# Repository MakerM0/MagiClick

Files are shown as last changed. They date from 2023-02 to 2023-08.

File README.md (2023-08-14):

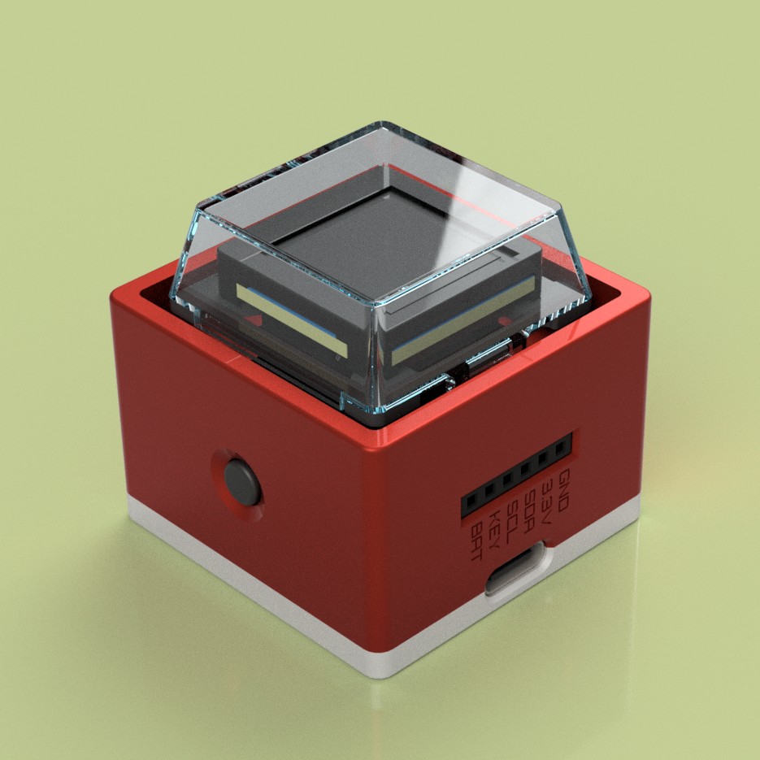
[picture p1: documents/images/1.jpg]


<p align="center">
    <br>
    
    <br>
</p>
<p align="center">   
    
      
</p>

# [MagiClick](https://hackaday.io/project/188183-magiclick-a-mechanical-button-with-screen)

[GitHub - MakerM0/MagiClick: A button](https://github.com/MakerM0/MagiClick)

The project uses [WCH&#39;s CH582F](https://www.wch.cn/products/CH583.html), a RISC-V chip, which supports BLE. The SDK comes with a multitasking system TMOS, which is very convenient for writing code.

The button can implement a variety of functions.
For example:

- Shutter via BLE
- Stopwatch
- Clock
- Pomodoro
- Music playback controller via BLE
- counter
- Random numbers
- 

It includes an expansion interface to support communication with I2C devices, such as temperature and humidity monitoring, light monitoring, etc.
You can achieve more depending on your needs.

## Guide

Power on: Press and hold the left button

Power off: In the function menu interface, hit the keys three times in a row

Switch function: On the function menu interface, press the side button to switch left and right

Return to the function options page: In general, press and hold the left or right button

Enter the function: The general situation is to press and hold the middle button

Use the apk under the software folder to synchronize time

## Firmware

IDE: [MounRiver Stuido](http://www.mounriver.com/download)

### How to download the firmware

TOOL: WCHISPStudio

While holding down the right button, press the left button to turn on the power, and you can enter the download mode

## Note

The current low-power strategy is to shut down the power directly. The time is not saved after the shutdown action. Please note.

In the future, standby mode will be adopted to maintain low power consumption and time functions.

## Mechanical

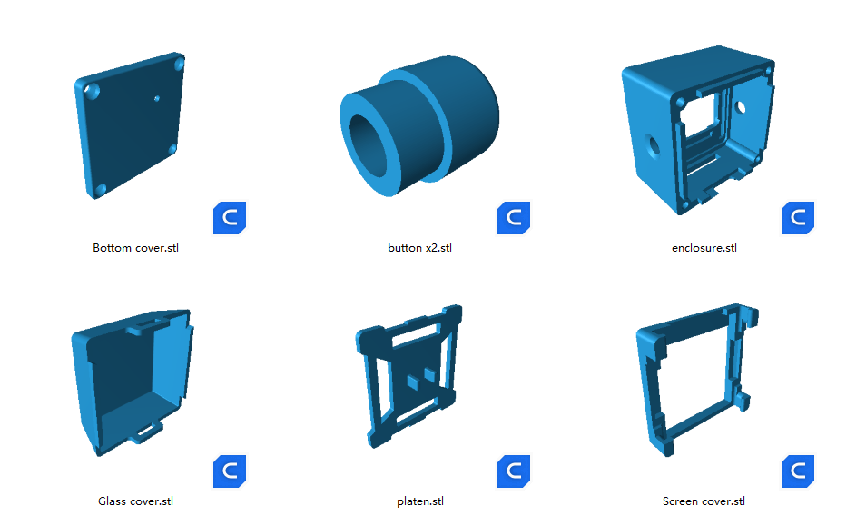
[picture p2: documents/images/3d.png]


The above file can be printed using a 3D printer.

The Glass cover must be transparent.

For Screen cover, black printing is recommended.

The screw hole is not used yet, please use glue to fix it.

I'll update the file that uses the screw holes when I'm free, hopefully not for too long.

## Images

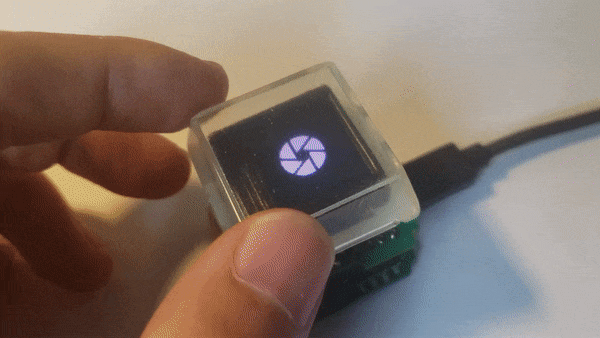
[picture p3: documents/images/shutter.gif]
shutter


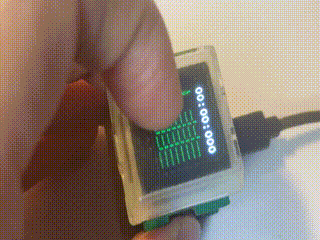
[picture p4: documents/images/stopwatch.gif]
stopwatch


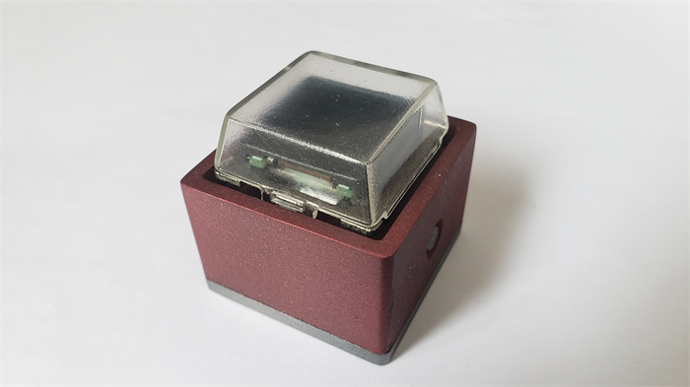
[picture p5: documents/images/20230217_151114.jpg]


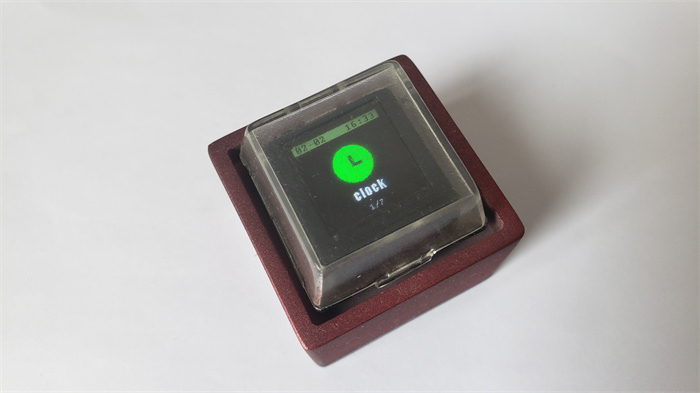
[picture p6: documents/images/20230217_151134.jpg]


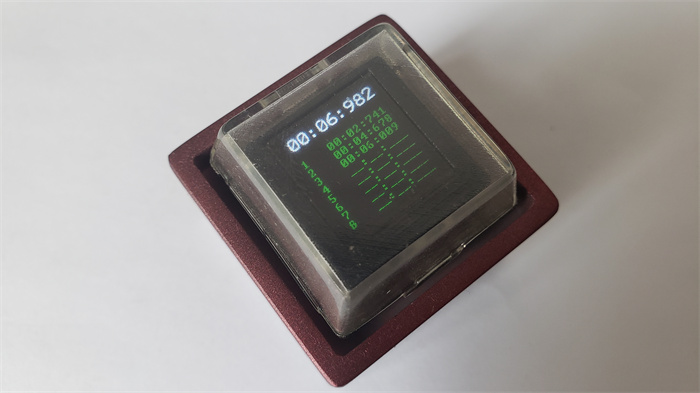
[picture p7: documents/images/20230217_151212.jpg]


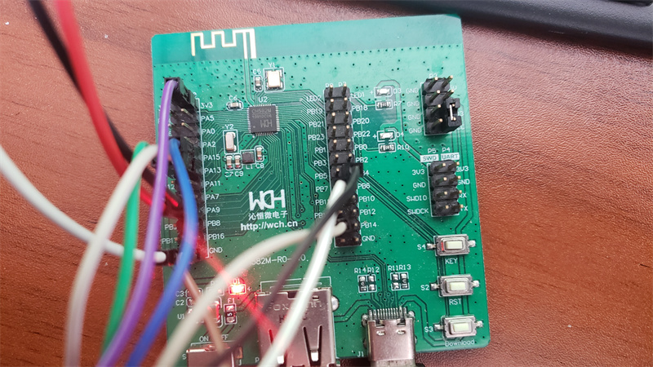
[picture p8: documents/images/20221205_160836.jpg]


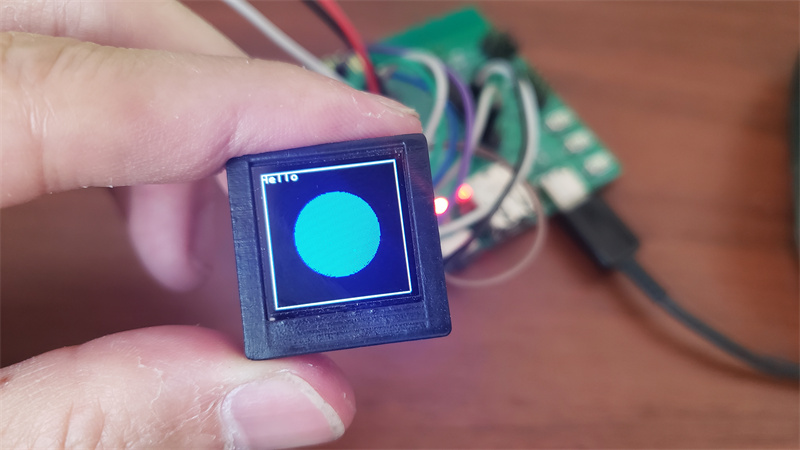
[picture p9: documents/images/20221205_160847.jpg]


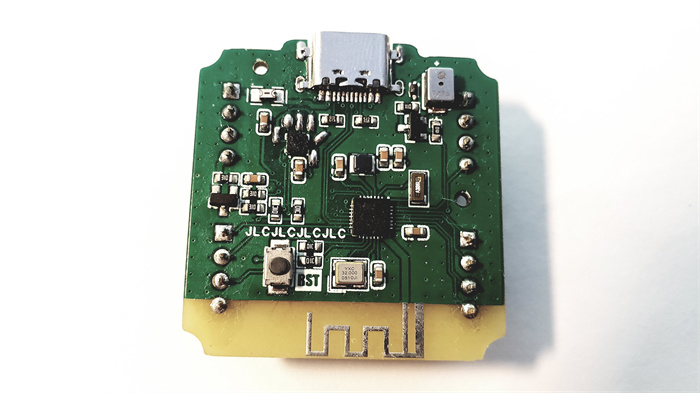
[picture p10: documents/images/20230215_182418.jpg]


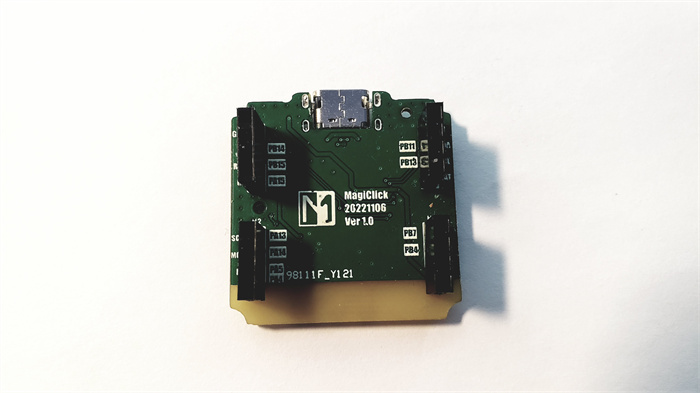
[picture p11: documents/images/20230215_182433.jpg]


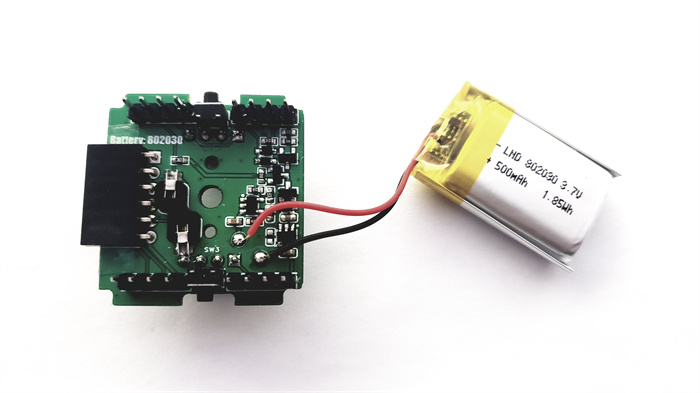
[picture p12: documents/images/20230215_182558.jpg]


## License

(hardware/mechanical)https://creativecommons.org/licenses/by-nc-nd/4.0

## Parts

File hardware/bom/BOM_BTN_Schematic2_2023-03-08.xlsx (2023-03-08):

No. | Quantity | Comment | Designator | Footprint | Value | Manufacturer Part | Manufacturer
1 | 2 | 10uF | C10,C11 | C0603 | 10uF | CL10A106KP8NNNC | SAMSUNG(三星)
2 | 2 | 1uF | C12,C13 | C0603 | 1uF | CL10A105KB8NNNC | SAMSUNG(三星)
3 | 3 | 1N5819WS | D1,D2,D3 | SOD-323_L1.8-W1.3-LS2.5-RD |  | 1N5819WS | Hottech(合科泰)
4 | 2 | 2.54-1*4P母 | H1,H2 | HDR-TH_4P-P2.54-V-F |  | 2.54-1*4P母 | BOOMELE(博穆精密)
5 | 4 | KH-2.54PH180-1X4P-L11.5 | H3,H4,H7,H8 | HDR-TH_4P-P2.54-V-M |  | KH-2.54PH180-1X4P-L11.5 | kinghelm(金航标)
6 | 1 | A2541HWR-6P | H5 | HDR-TH_6P-P2.54-H-W8.6_A2541HWR-6P |  | A2541HWR-6P | CJT(长江连接器)
7 | 1 | 19-217/R6C-AL1M2VY/3T | LED1 | LED0603-R-RD |  | 19-217/R6C-AL1M2VY/3T | EVERLIGHT(台湾亿光)
8 | 2 | AO3401A | Q1,Q2 | SOT-23_L2.9-W1.3-P1.90-LS2.4-BR |  | AO3401A | AOS
9 | 1 | AO3400A | Q3 | SOT-23-3_L2.9-W1.6-P1.90-LS2.8-BR |  | AO3400A | AOS
10 | 3 | 10kΩ | R1,R5,R6 | R0603 | 10kΩ | 0603WAF1002T5E | UNI-ROYAL(厚声)
11 | 3 | 100kΩ | R2,R3,R4 | R0603 | 100kΩ | 0603WAF1003T5E | UNI-ROYAL(厚声)
12 | 1 | 1kΩ | R16 | R0603 | 1kΩ | 0603WAF1001T5E | UNI-ROYAL(厚声)
13 | 1 | 0603WAF1601T5E | R17 | R0603 |  | 0603WAF1601T5E | UNI-ROYAL(厚声)
14 | 2 | ST-1109-3-5 | SW2,SW3 | SW-TH_ST-1109-3-5 |  | ST-1109-3-5 | RISHENG(日昇)
15 | 1 | CPG135001D03 | SW4 | 凯华矮轴 复合 热插拔 |  | CPG135001D03 | Kailh(凯华)
16 | 1 | TP4054-42-SOT25R | U1 | SOT-23-5_L3.0-W1.7-P0.95-LS2.8-BR |  | TP4054-42-SOT25R | TOPPOWER(南京拓微)
17 | 1 | ME6214C33M5G | U2 | SOT-23-5_L3.0-W1.7-P0.95-LS2.8-BR |  | ME6214C33M5G | MICRONE(南京微盟)

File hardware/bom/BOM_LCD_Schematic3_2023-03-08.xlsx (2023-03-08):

No. | Quantity | Comment | Designator | Footprint | Value | Manufacturer Part | Manufacturer
1 | 1 | 100nF | C1 | C0603 | 100nF | CL10B104KB8NNNC | SAMSUNG(三星)
2 | 1 | 1uF | C2 | c0603 | 1uF | CC0603KRX5R8BB105 | YAGEO(国巨)
3 | 2 | KH-2.54PH180-1X4P-L11.5 | H1,H2 | HDR-TH_4P-P2.54-V-M |  | KH-2.54PH180-1X4P-L11.5 | kinghelm(金航标)
4 | 1 | SS8050 | Q1 | SOT-23-3_L2.9-W1.3-P1.90-LS2.4-BR |  | SS8050 | CJ（江苏长电/长晶）
5 | 1 | 10Ω | R2 | R0603 | 10Ω | 0603WAF100JT5E | UNI-ROYAL(厚声)
6 | 1 | 10kΩ | R4 | R0603 | 10kΩ | 0603WAF1002T5E | UNI-ROYAL(厚声)
7 | 1 | 1kΩ | R5 | R0603 | 1kΩ | 0603WAF1001T5E | UNI-ROYAL(厚声)
8 | 1 |  | U1 | TFT_0.85inch_128*128

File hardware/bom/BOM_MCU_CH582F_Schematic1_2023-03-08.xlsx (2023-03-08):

No. | Quantity | Comment | Designator | Footprint | Value | Manufacturer Part | Manufacturer
1 | 1 | DET402-G-1 | BUZZER2 | BUZ-SMD_L4.0-W3.0-LS4.5-FD |  | DET402-G-1
2 | 4 | 2.2uF | C1,C2,C7,C8 | C0603 | 2.2uF | CL10A225KO8NNNC | SAMSUNG(三星)
3 | 4 | 100nF | C3,C4,C5,C6 | C0603 | 100nF | CL10B104KB8NNNC | SAMSUNG(三星)
4 | 1 | 1N4148WT | D3 | SOD-523_L1.2-W0.8-LS1.6-RD |  | 1N4148WT | onsemi(安森美)
5 | 1 | JK-SMD0805-050/6V | F1 | F0805 |  | JK-SMD0805-050/6V | JK(金科)
6 | 4 | 2.54-1*4P母 | H1,H2,H3,H4 | HDR-TH_4P-P2.54-V-F |  | 2.54-1*4P母 | BOOMELE(博穆精密)
7 | 6 | 2短路点 | J1,J2,J3,J4,J5,J6 | 短路接口
8 | 1 | 22uH | L1 | IND-SMD_L2.5-W2.0_FNR252012S | 22uH | FNR252012S220MT | cjiang(长江微电)
9 | 1 | AO3400A | Q1 | SOT-23_L2.9-W1.3-P1.90-LS2.4-BR |  | AO3400A | BORN伯恩半导体
10 | 1 | AO3401A | Q2 | SOT-23_L2.9-W1.3-P1.90-LS2.4-BR |  | AO3401A | AOS
11 | 2 | 5.1kΩ | R1,R2 | R0603 | 5.1kΩ | 0603WAF5101T5E | UNI-ROYAL(厚声)
12 | 4 | 10kΩ | R3,R4,R9,R10 | R0603 | 10kΩ | 0603WAF1002T5E | UNI-ROYAL(厚声)
13 | 3 | 1MΩ | R5,R6,R29 | R0603 | 1MΩ | 0603WAF1004T5E | UNI-ROYAL(厚声)
14 | 1 | 100kΩ | R7 | R0603 | 100kΩ | 0603WAF1003T5E | UNI-ROYAL(厚声)
15 | 1 | 10Ω | R8 | R0603 | 10Ω | 0603WAF100JT5E | UNI-ROYAL(厚声)
16 | 1 | TSA010A2026B | SW2 | SW-SMD_L4.0-W3.0-LS5.0 |  | TSA010A2026B | BZCN(博众电气)
17 | 1 | CH582F | U2 | QFN-28_L4.0-W4.0-P0.40-BL-EP2.8 |  | CH582F | WCH(南京沁恒)
18 | 1 | KXTJ3-1057 | U3 | LGA-12_L2.0-W2.0-P0.50-BL |  | KXTJ3-1057 | ROHM(罗姆)
19 | 1 | TYPE-C 16P CB1.6 073 | USB4 | USB-C-SMD_SHOU_TYPE-C-16P-CB1.6 |  | TYPE-C 16P CB1.6 073 | SHOU HAN(首韩)
20 | 1 | - | X1 | CRYSTAL-SMD_4P-L3.2-W2.5-BL | - | TZ0375A | TST(嘉硕)
21 | 1 | - | X2 | OSC-SMD_L3.2-W1.5 | - | DST310S 32.768KHz | KDS大真空

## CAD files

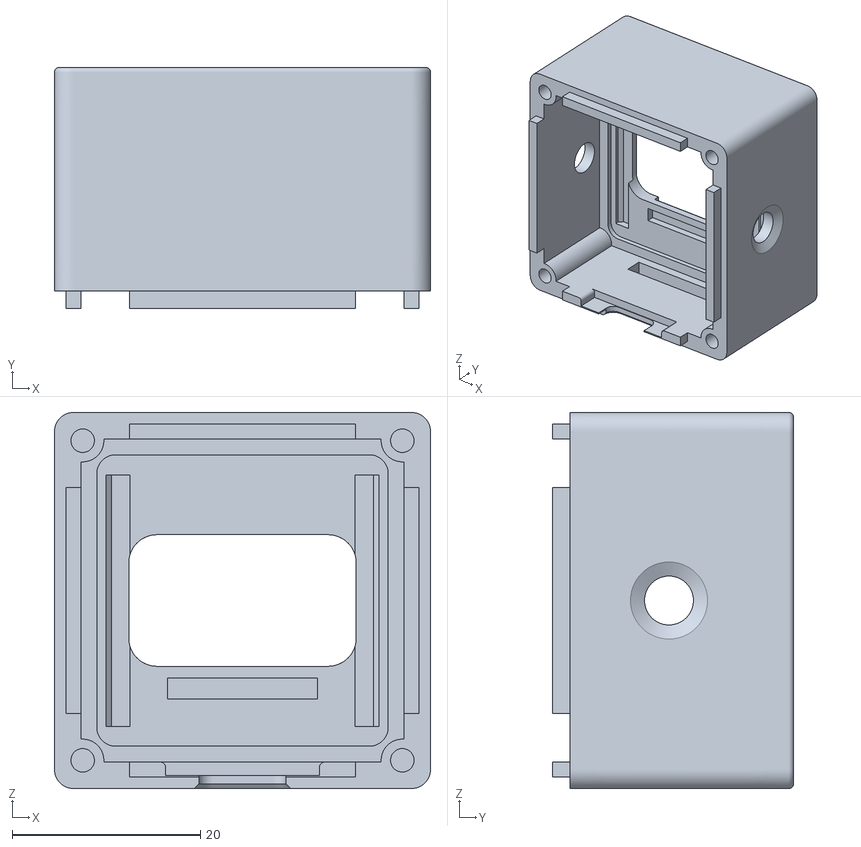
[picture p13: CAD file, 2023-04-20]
mechanical/v1.0/enclosure.stl
40.0 x 25.6 x 40.0

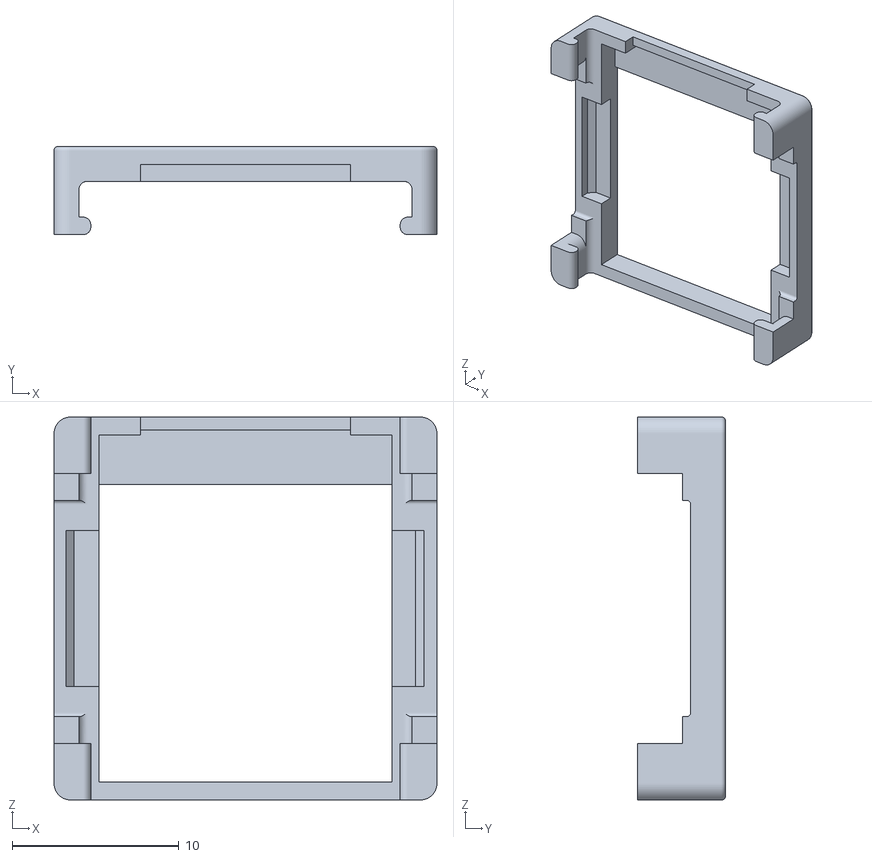
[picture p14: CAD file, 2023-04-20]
mechanical/v1.0/Screen cover.stl
23.0 x 5.30 x 23.0

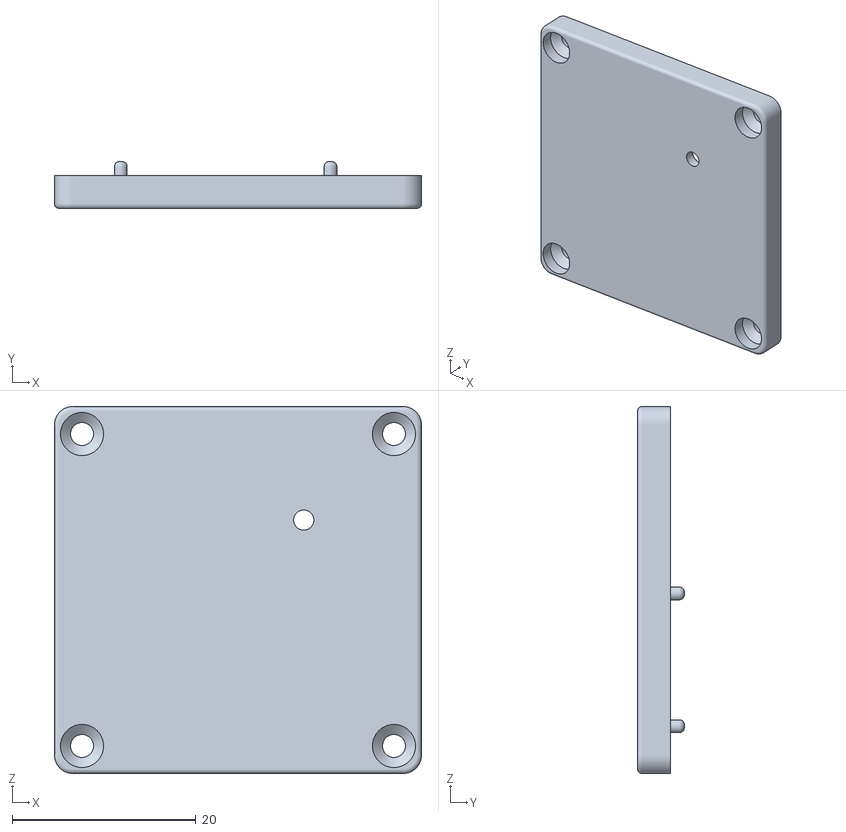
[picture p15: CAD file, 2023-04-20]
mechanical/v1.0/Bottom cover.stl
40.0 x 5.10 x 40.0

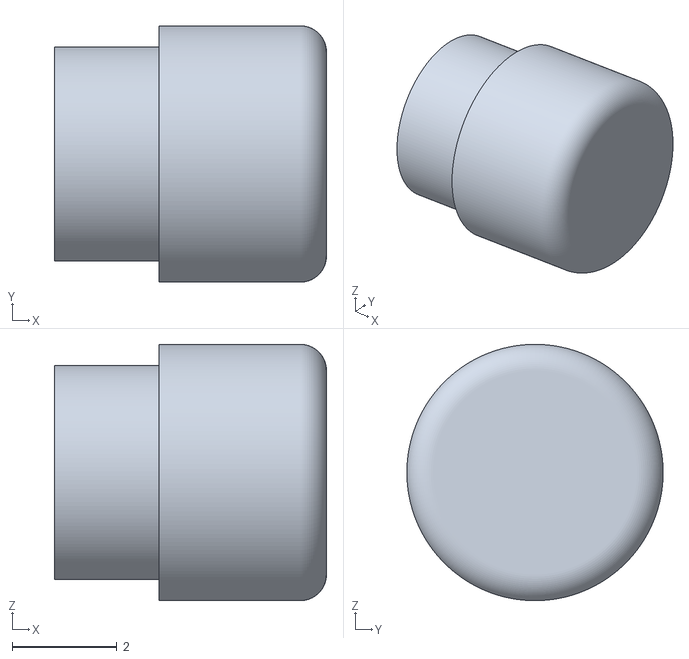
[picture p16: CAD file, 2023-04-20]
mechanical/v1.0/button x2.stl
5.20 x 4.90 x 4.90

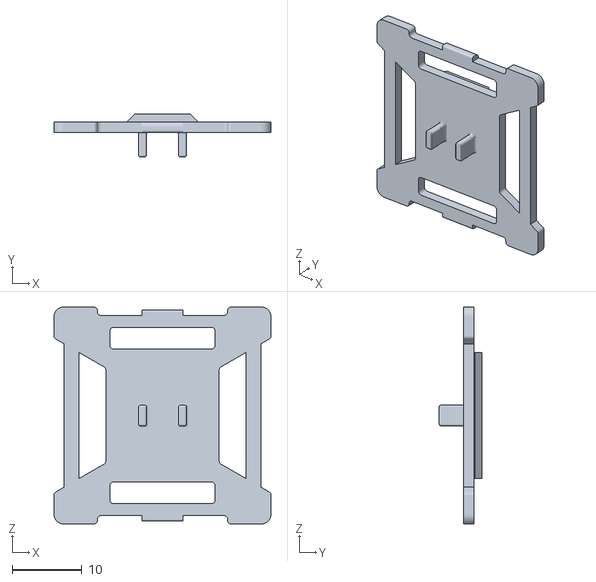
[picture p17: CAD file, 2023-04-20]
mechanical/v1.0/platen.stl
31.0 x 6.10 x 31.0

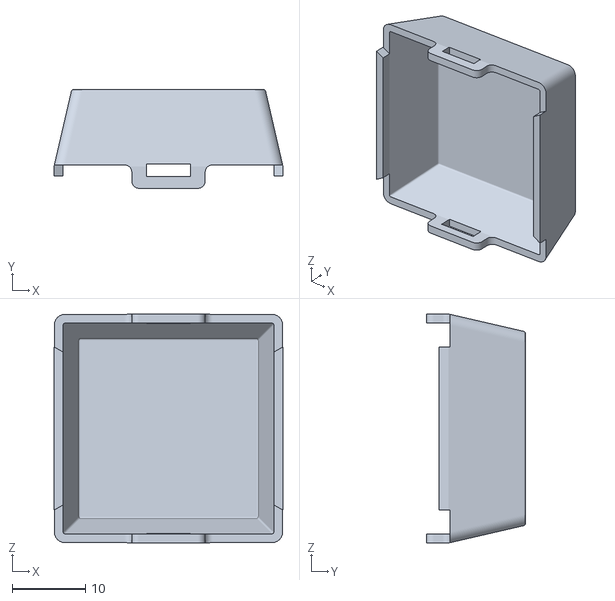
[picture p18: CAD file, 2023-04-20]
mechanical/v1.0/Glass cover.stl
31.2 x 13.4 x 31.2

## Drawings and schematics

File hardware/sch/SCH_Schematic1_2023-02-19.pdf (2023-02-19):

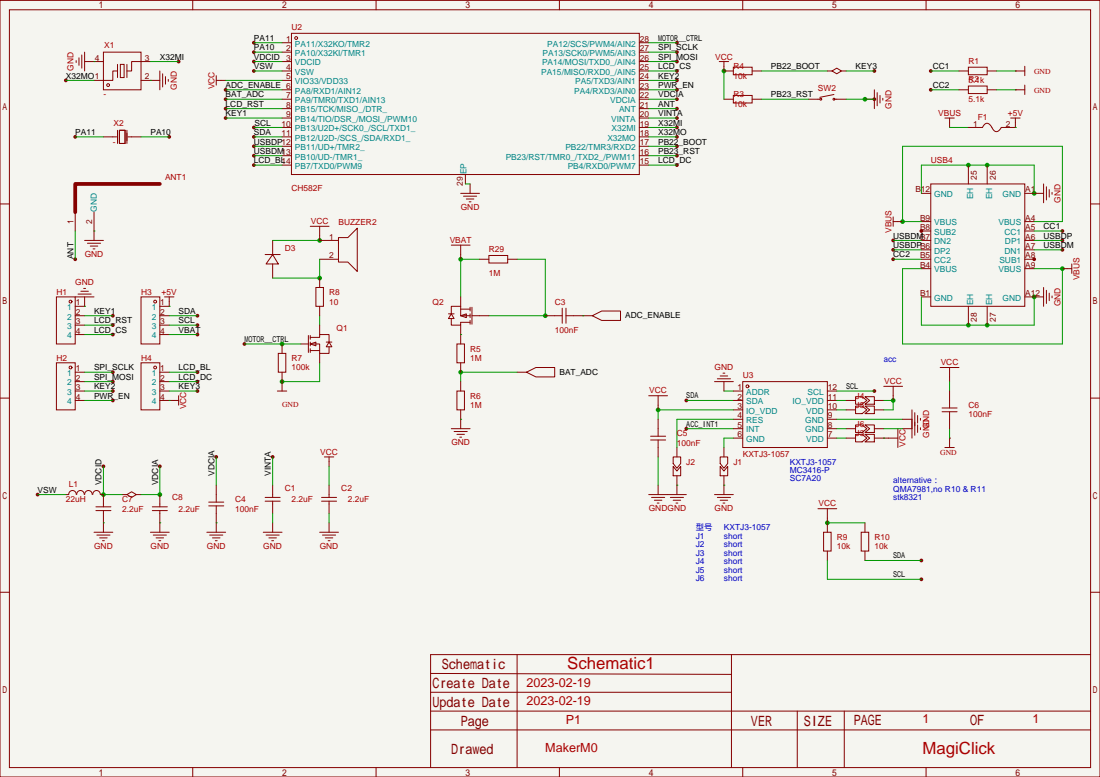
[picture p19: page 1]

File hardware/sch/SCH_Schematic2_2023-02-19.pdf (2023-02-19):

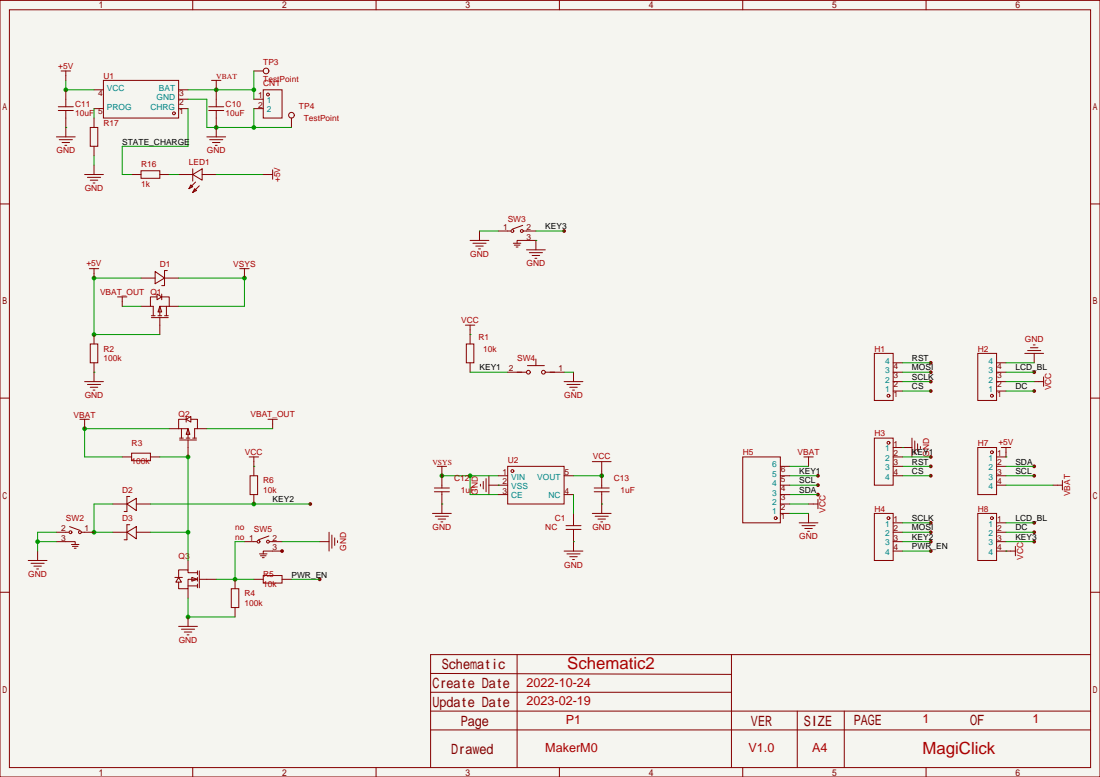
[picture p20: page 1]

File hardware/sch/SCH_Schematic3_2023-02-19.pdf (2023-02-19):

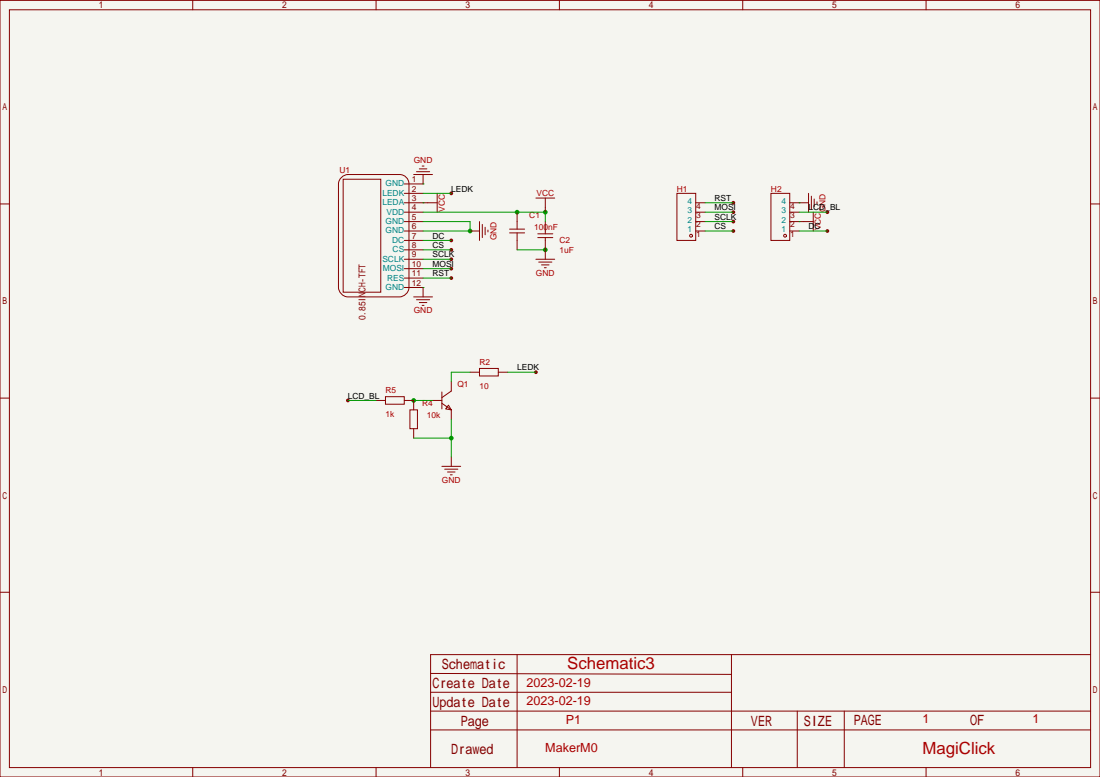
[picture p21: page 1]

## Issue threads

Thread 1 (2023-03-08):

BOM file

happytm, 2023-03-08:
Great project for great chip.

Instead of using USB-C, I want to use directly plugged USB-A PCB for simplicity. Is it OK to program the chip with USB-A PCB? If So what pins should I use?

Can you please publish BOM file or parts list?

Thanks.

MakerM0, 2023-03-08:
Thanks！
It can be replaced with USB-A, and there is basically no need to modify the line.
I'll update the BOM to the repository later.

happytm, 2023-03-08:
Thank you for your quick reply.

happytm, 2024-01-05:
@MakerM0 Can you please publish .sch and .pcb files for main PCB with CH582F chip on it? If not can you advice me how to achieve following goals?

1. I wanted to build lowest cost BLE board to test 1KM range of chip using coded PHY @125K.
2. I wanted to remove USB-C type connector and use USB-A pcb type connector for simplicity and low cost.
3. I wanted to provide pads for SMA/UFL connector for external antenna to test long range of this chip.
4. If possible, I would like to get rid of any external LDO and use only button cell battery for testing and while flashing the
   board I can use couple of diaodes on board to drop voltage of 5V to 3.6V. Or is there any other way to drop voltage when
   flashing?
5. I will be adding NTC thermistor and analog light sensor on board and send this data via BLE. If you know any inexpensive
   parts for this purpose please let me know.

I tried to recreate project from your PDF schematics but I am not very good at creating PCB from scratch and routing it properly.

I will appreciate any help or advice you can provide.
Thank you.

MakerM0, 2024-01-06:
@happytm Sorry, I am using an EDA software that does not support exporting files in this format.

USB-A is OK.
The LDO can be removed and replaced with several diodes.
I don't have a suitable sensor to recommend.
This size 20X20 should be easily satisfied.

happytm, 2024-01-07:
Thank you.

Closed 2024-01-07.

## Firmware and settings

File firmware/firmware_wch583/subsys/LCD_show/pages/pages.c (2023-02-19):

#include "pages.h"
#include "LCD_show/manager/manager.h"

#include "LCD_show/pages/clock/clock.h"
#include "LCD_show/pages/media/media.h"
#include "LCD_show/pages/stopwatch/stopwatch.h"
#include "LCD_show/pages/shutter/shutter.h"
#include "LCD_show/pages/counter/counter.h"
#include "LCD_show/pages/lucky/lucky.h"
#include "LCD_show/pages/temperature/temperature.h"

//需要添加自己的功能页面
page_t *pages[] =
{ &page_main, &page_clock, &page_media, &page_stopwatch, &page_shutter,
		&page_counter, &page_lucky,&page_temperature

};

static const uint8_t pages_num = ARRAY_SIZE(pages);

static int16_t page_index = 1;
static int16_t page_index_old = 0;


static void dispBar()
{
//	UG_FillFrame(0, 0, 127, 12, C_DARK_OLIVE_GREEN);

	char buffer[50];
	strftime(buffer, 100, "%F %T", mytime);

	uint16_t year = mytime->tm_year + 1900;
	uint16_t yday = mytime->tm_yday;
	uint8_t month = mytime->tm_mon + 1;
	uint8_t week = mytime->tm_wday + 1;
	uint8_t day = mytime->tm_mday;
	uint8_t hour = mytime->tm_hour;
	uint8_t minute = mytime->tm_min;
	uint8_t second = mytime->tm_sec;

	UG_FontSetTransparency(0);

	UG_FontSelect(FONT_8X12);

	UG_SetBackcolor(C_DARK_OLIVE_GREEN);
	UG_SetForecolor(C_BLACK);


	snprintf(buffer,16,"%02d-%02d",month,  day);
	UG_PutString(5, 1, buffer);

	snprintf(buffer,16,"%02d:%02d",hour,  minute);
	UG_PutString(80, 1, buffer);

//	snprintf(buffer,16,"%02d:02%d",month,  day);
//	UG_PutString(44, 0, buffer);




	UG_FontSetTransparency(1);

}



static void init(void *data)
{

	manager.index = 0;

}

static void enter(void *data)
{
	char buffer[10];
	uint16_t width = pages[page_index]->icon_width;
	uint16_t height = pages[page_index]->icon_height;

	PRINT("enter:%d  ", page_index);

	UG_FillFrame(0, 0, 127, 12, C_DARK_OLIVE_GREEN);
	UG_FillFrame(0, 13, 127, 127, C_BLACK);
//	UG_FillScreen(C_BLACK);

	if (pages[page_index]->icon)
	{
		UG_SetBackcolor(C_BLACK);
		UG_SetForecolor(C_DIM_GRAY);
		UG_FontSelect(FONT_6X10);
		UG_FontSetTransparency(0);
		sprintf(buffer, "%d/%d  ", page_index, pages_num - 1);

		UG_PutString(55, 118, buffer);
		UG_FontSetTransparency(1);


		UG_FontSelect(FONT_impact_14X18);
		UG_SetForecolor(C_DARK_GRAY);
		uint16_t title_width = UG_GetStringWidth(pages[page_index]->title_en);
		UG_PutString((LCD_W - title_width) / 2, 92,
				pages[page_index]->title_en);

		LCD_DrawMonoImgFast((LCD_W - width) / 2, 25, width, height,
				pages[page_index]->icon, C_GREEN, C_BLACK);
	}


	manager_startEventOnce(5);

	manager_setBusy(false);
}

void switchpages()
{
	char buffer[10];

	uint16_t width;
	uint16_t height;

	width = pages[page_index]->icon_width;
	height = pages[page_index]->icon_height;

//    UG_FillFrame(0, 95, 127, 95+UG_GetFontHeight(FONT_impact_14X18)+3, tmos_rand()>>20);
	UG_FillFrame(0, 92, 127, 112, C_BLACK);
	UG_SetBackcolor(C_BLACK);
	UG_FontSelect(FONT_6X10);
	UG_SetForecolor(C_DIM_GRAY);
	UG_FontSetTransparency(0);
	sprintf(buffer, "%d/%d   ", page_index, pages_num - 1);
	UG_PutString(55, 118, buffer);
			UG_FontSetTransparency(1);

	UG_SetForecolor(C_DARK_GRAY);
	UG_SetBackcolor(C_BLACK);
	UG_FontSelect(FONT_impact_14X18);
	uint16_t title_width_old = UG_GetStringWidth(
			pages[page_index_old]->title_en);
	uint16_t title_width = UG_GetStringWidth(pages[page_index]->title_en);
	UG_PutString((LCD_W - title_width) / 2, 92, pages[page_index]->title_en);

	LCD_DrawMonoImgFast((LCD_W - width) / 2, 25, width, height,
			pages[page_index]->icon, tmos_rand() >> 16, C_BLACK);

}

static void switchNext()
{
	page_index_old = page_index;
	page_index++;
	if (page_index == pages_num)
		page_index = 1;
}

static void switchPrev()
{
	page_index_old = page_index;
	page_index--;
	if (page_index == 0)
		page_index = pages_num - 1;
}
#include "hidconsumer.h"
void poweroff(void )
{
	GPIOA_ResetBits(GPIO_Pin_4);
	GPIOA_ModeCfg(GPIO_Pin_4,GPIO_ModeOut_PP_5mA);
	DelayMs(100);
}
static void loop(void *data)
{

	KEY_TYPE key = HAL_KeyGet();
//    if(key!=KEY_NONE)PRINT("%d\r\n ",key);

//    if(key!=KEY_NONE)tmos_set_event(BEEP_TaskID, BEEP_SHOCK_EVT);
	switch (key)
	{

	case KEY1_LONG:
		manager.index = page_index;
		manager_switchToChild(); //进入子项目
		break;

	case KEY2_DOWN:                //上一功能
		switchPrev();
		//发送切换事件
		tmos_set_event(show_TaskID, SHOW_SWITCH_PAGES_EVENT);

		break;

	case KEY3_DOWN:                  //下一功能
		switchNext();
		//发送切换事件
		tmos_set_event(show_TaskID, SHOW_SWITCH_PAGES_EVENT);

		break;
	case KEY1_DOUBLE:
		case KEY1_TRIPLE:
		case KEY2_DOUBLE:
			case KEY2_TRIPLE:
	case KEY3_DOUBLE:
	case KEY3_TRIPLE: poweroff();
		break;
	default:
		break;
	}

}
static void event(void *data)
{
	dispBar();
	manager_startEventOnce(10000);
}

static void quit(void *data)
{

	manager_setBusy(true);

	// free(buffer);
}

page_t page_main =
{ .init = init, .enter = enter, .exit = quit, .loop = loop, .event = event,
		.title_en = "main", .title_cn = "主页", .icon = NULL, .icon_width = 0,
		.icon_height = 0, .sleep_enable = true, .wakeup_btn_effect_enable =
				false, .acc_enable = true,

};

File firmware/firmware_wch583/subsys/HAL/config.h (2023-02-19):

/********************************** (C) COPYRIGHT *******************************
 * File Name          : CONFIG.h
 * Author             : WCH
 * Version            : V1.10
 * Date               : 2019/11/05
 * Description        : 配置说明及默认值，建议在工程配置里的预处理中修改当前值
 *******************************************************************************/

/******************************************************************************/
#ifndef __CONFIG_H
#define __CONFIG_H

#define	ID_CH573							0x83

#define CHIP_ID								ID_CH583

#include <stdint.h>
#ifdef CH57xBLE_ROM
#include "CH58xBLE_ROM.H"
#else
#include "CH58xBLE_LIB.H"
#include "CH583SFR.h"
#endif
/*********************************************************************
 【MAC】
 BLE_MAC											- 是否自定义蓝牙Mac地址 ( 默认:FALSE - 使用芯片Mac地址 )，需要在main.c修改Mac地址定义

 【DCDC】
 DCDC_ENABLE                  - 是否使能DCDC ( 默认:FALSE )

 【SLEEP】
 HAL_SLEEP   									- 是否开启睡眠功能 ( 默认:FALSE )
 WAKE_UP_RTC_MAX_TIME					- 等待32M晶振稳定时间，根据不同睡眠类型取值可分为： 睡眠模式/下电模式         -	45(默认)
                                                                                                                                                                                        暂停模式					-	45
                                                                                                                                                                                        空闲模式					-	5
 
 【TEMPERATION】
 TEM_SAMPLE										- 是否打开根据温度变化校准的功能，单次校准耗时小于10ms( 默认:TRUE )
 
 【CALIBRATION】
 BLE_CALIBRATION_ENABLE				- 是否打开定时校准的功能，单次校准耗时小于10ms( 默认:TRUE )
 BLE_CALIBRATION_PERIOD				- 定时校准的周期，单位ms( 默认:120000 ) 
 
 【SNV】
 BLE_SNV    				          - 是否开启SNV功能，用于储存绑定信息( 默认:TRUE )
 BLE_SNV_ADDR    					    - SNV信息保存地址，使用data flash最后( 默认:0x77E00 )

 【RTC】
 CLK_OSC32K										- RTC时钟选择，如包含主机角色必须使用外部32K( 默认:0 外部(32768Hz)，1：内部(32000Hz)，2：内部(32768Hz) )

 【MEMORY】
 BLE_MEMHEAP_SIZE  						- 蓝牙协议栈使用的RAM大小，不小于6K ( 默认:(1024*6) )

 【DATA】
 BLE_BUFF_MAX_LEN							- 单个连接最大包长度( 默认:27 (ATT_MTU=23)，取值范围[27~251] )
 BLE_BUFF_NUM									- 控制器缓存的包数量( 默认:5 )
 BLE_TX_NUM_EVENT							- 单个连接事件最多可以发多少个数据包( 默认:1 )
 BLE_TX_POWER									- 发射功率( 默认:LL_TX_POWEER_0_DBM (0dBm) )
 
 【MULTICONN】
 PERIPHERAL_MAX_CONNECTION	  - 最多可同时做多少从机角色( 默认:1 )
 CENTRAL_MAX_CONNECTION				- 最多可同时做多少主机角色( 默认:3 )
 **********************************************************************/

/*********************************************************************
 * 默认配置值
 */
#ifndef BLE_MAC
#define BLE_MAC											TRUE
#endif
#ifndef DCDC_ENABLE
#define DCDC_ENABLE                                     TRUE
#endif
#ifndef HAL_SLEEP
#define HAL_SLEEP										FALSE
#endif
#ifndef WAKE_UP_RTC_MAX_TIME
#define WAKE_UP_RTC_MAX_TIME				            45
#endif
#ifndef HAL_KEY
#define HAL_KEY											TRUE
#endif
#ifndef HAL_ADC
#define HAL_ADC                                         FALSE
#endif
#ifndef HAL_LED
#define HAL_LED											FALSE
#endif
#ifndef TEM_SAMPLE
#define TEM_SAMPLE									    TRUE
#endif
#ifndef BLE_CALIBRATION_ENABLE
#define BLE_CALIBRATION_ENABLE			                TRUE
#endif
#ifndef BLE_CALIBRATION_PERIOD
#define BLE_CALIBRATION_PERIOD			                120000
#endif
#ifndef BLE_SNV
#define BLE_SNV											TRUE
#endif
#ifndef BLE_SNV_ADDR
#define BLE_SNV_ADDR								    0x77E00-FLASH_ROM_MAX_SIZE
#endif
#ifndef CLK_OSC32K
#define CLK_OSC32K									    0							// 该项请勿在此修改，必须在工程配置里的预处理中修改，如包含主机角色必须使用外部32K
#endif
#ifndef BLE_MEMHEAP_SIZE
#define BLE_MEMHEAP_SIZE						        (1024*6)
#endif
#ifndef BLE_BUFF_MAX_LEN
#define BLE_BUFF_MAX_LEN						        27
#endif
#ifndef BLE_BUFF_NUM
#define BLE_BUFF_NUM								    3
#endif
#ifndef BLE_TX_NUM_EVENT
#define BLE_TX_NUM_EVENT						        1
#endif
#ifndef BLE_TX_POWER
#define BLE_TX_POWER								    LL_TX_POWEER_0_DBM
#endif
#ifndef PERIPHERAL_MAX_CONNECTION
#define PERIPHERAL_MAX_CONNECTION		                1
#endif
#ifndef CENTRAL_MAX_CONNECTION
#define CENTRAL_MAX_CONNECTION			                3
#endif

extern u32 MEM_BUF[BLE_MEMHEAP_SIZE / 4];
extern uint8_t MacAddr[6];


#endif

/******************************* endfile @ config ******************************/

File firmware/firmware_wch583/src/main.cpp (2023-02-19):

/********************************** (C) COPYRIGHT *******************************
* File Name          : main.c
* Author             : WCH
* Version            : V1.1
* Date               : 2020/08/06
* Description        : 外设从机应用主函数及任务系统初始化
*******************************************************************************/

/******************************************************************************/
/* 头文件包含 */

extern "C" {
#include "CH58x_common.h"
#include "HAL/config.h"
#include "HAL/HAL.h"
#include "HAL_FLASH/include/easyflash.h"
#include "peripheral.h"
#include "LCD_show/show_task.h"
#include "BLE/heartrate.h"
#include "BLE/dfu.h"
#include "BLE/CTS.h"
#include "BLE/battery.h"

}

#include "sensor/sensor_task.h"
#include "DRV/DRV.h"


#include "HAL/BEEP.h"



/*********************************************************************
 * GLOBAL TYPEDEFS
 */
__attribute__((aligned(4))) u32 MEM_BUF[BLE_MEMHEAP_SIZE/4];

#if (defined (BLE_MAC)) && (BLE_MAC == TRUE)
uint8_t MacAddr[6] = {0x84,0xC2,0xE4,0x03,0x02,0x32};
#endif



/*******************************************************************************
* Function Name  : Main_Circulation
* Description    : 主循环
* Input          : None
* Output         : None
* Return         : None
*******************************************************************************/
__attribute__((section(".highcode")))
void Main_Circulation()
{
  while(1){
    TMOS_SystemProcess( );
  }
}


/*******************************************************************************
* Function Name  : main
* Description    : 主函数
* Input          : None
* Output         : None
* Return         : None
*******************************************************************************/
int main( void ) 
{
  /*enable systick interrupt     */
  SysTick_Config(FREQ_SYS/1000);  //1ms

#if (defined (DCDC_ENABLE)) && (DCDC_ENABLE == TRUE)
  PWR_DCDCCfg( ENABLE );
#endif

//  GPIOA_ModeCfg( GPIO_Pin_All, GPIO_ModeIN_PD );
//  GPIOB_ModeCfg( GPIO_Pin_All, GPIO_ModeIN_PD );
#ifdef DEBUG
  GPIOA_SetBits(bTXD1);
  GPIOA_ModeCfg(bTXD1, GPIO_ModeOut_PP_5mA);
  UART1_DefInit();
#endif
  PRINT("123\r\n");
  DEBUG_Init();

  /*DataFlash初始化*/
  if( easyflash_init() != SUCCESS )
  {
    LOG_INFO("Date Flash init error!");
  }
  ef_print_env();

  CH58X_BLEInit( );
  HAL_Init( );
  Show_Task_Init();
//  Sensor_Task_Init();
//  DRV_Task_Init();
  BEEP_Task_Init();
//  GAPRole_PeripheralInit( );
//  Peripheral_Init();
//  Battery_Init();
//  HeartRate_Init();
//  CurrentTime_Init();
//  dfu_Init();

  Main_Circulation();
}




/******************************** endfile @ main ******************************/

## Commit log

2023-03-08 update bom
    [BOM_BTN_Schematic2_2023-03-08.xlsx, BOM_LCD_Schematic3_2023-03-08.xlsx, BOM_MCU_CH582F_Schematic1_2023-03-08.xlsx]
2023-04-20 update files
    [Bottom cover.stl, Glass cover.stl, Screen cover.stl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]
